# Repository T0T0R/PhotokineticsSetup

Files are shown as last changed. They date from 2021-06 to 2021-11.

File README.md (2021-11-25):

# PhotokineticsSetup
A microcontroller (STM32F103C8) drives at the same time an Hamamatsu lamp through its RS232 interface, and two flip mounts MFF101 via TTL inputs.

## Installation
This script works with Python 3.9.
The pySerial library must be installed in order to achieve serial communication with the microcontroler. This can be done by typing the following command in the system console:
```
python -m pip install pyserial
```
The Tkinter GUI is used in this program. There shouldn't be any need to install it since it is an integral part of most of Python installations.

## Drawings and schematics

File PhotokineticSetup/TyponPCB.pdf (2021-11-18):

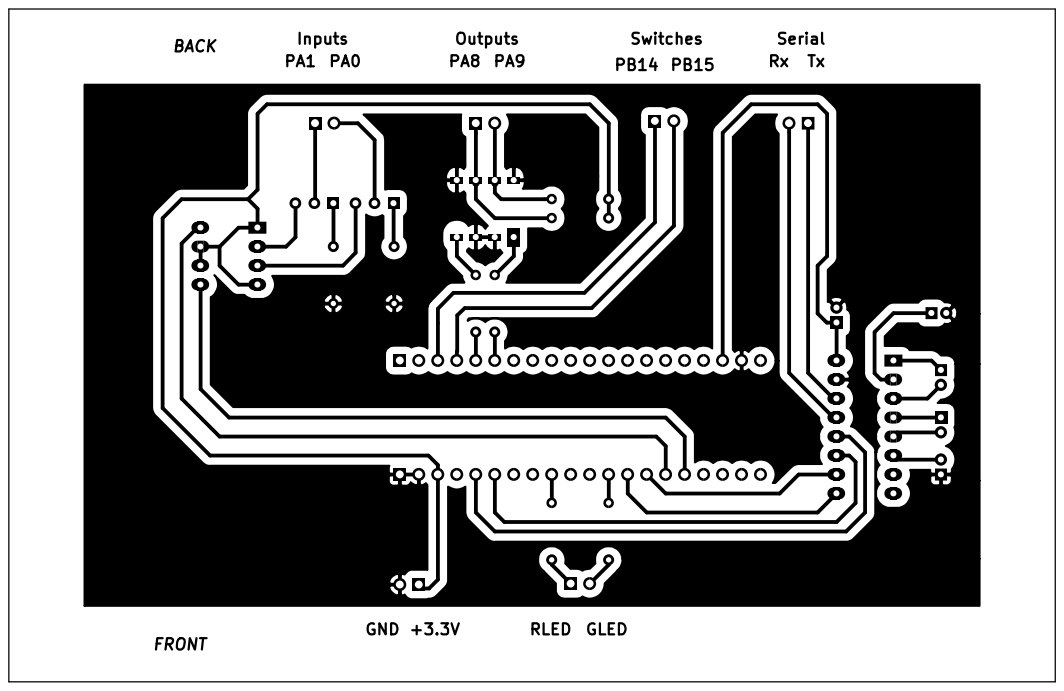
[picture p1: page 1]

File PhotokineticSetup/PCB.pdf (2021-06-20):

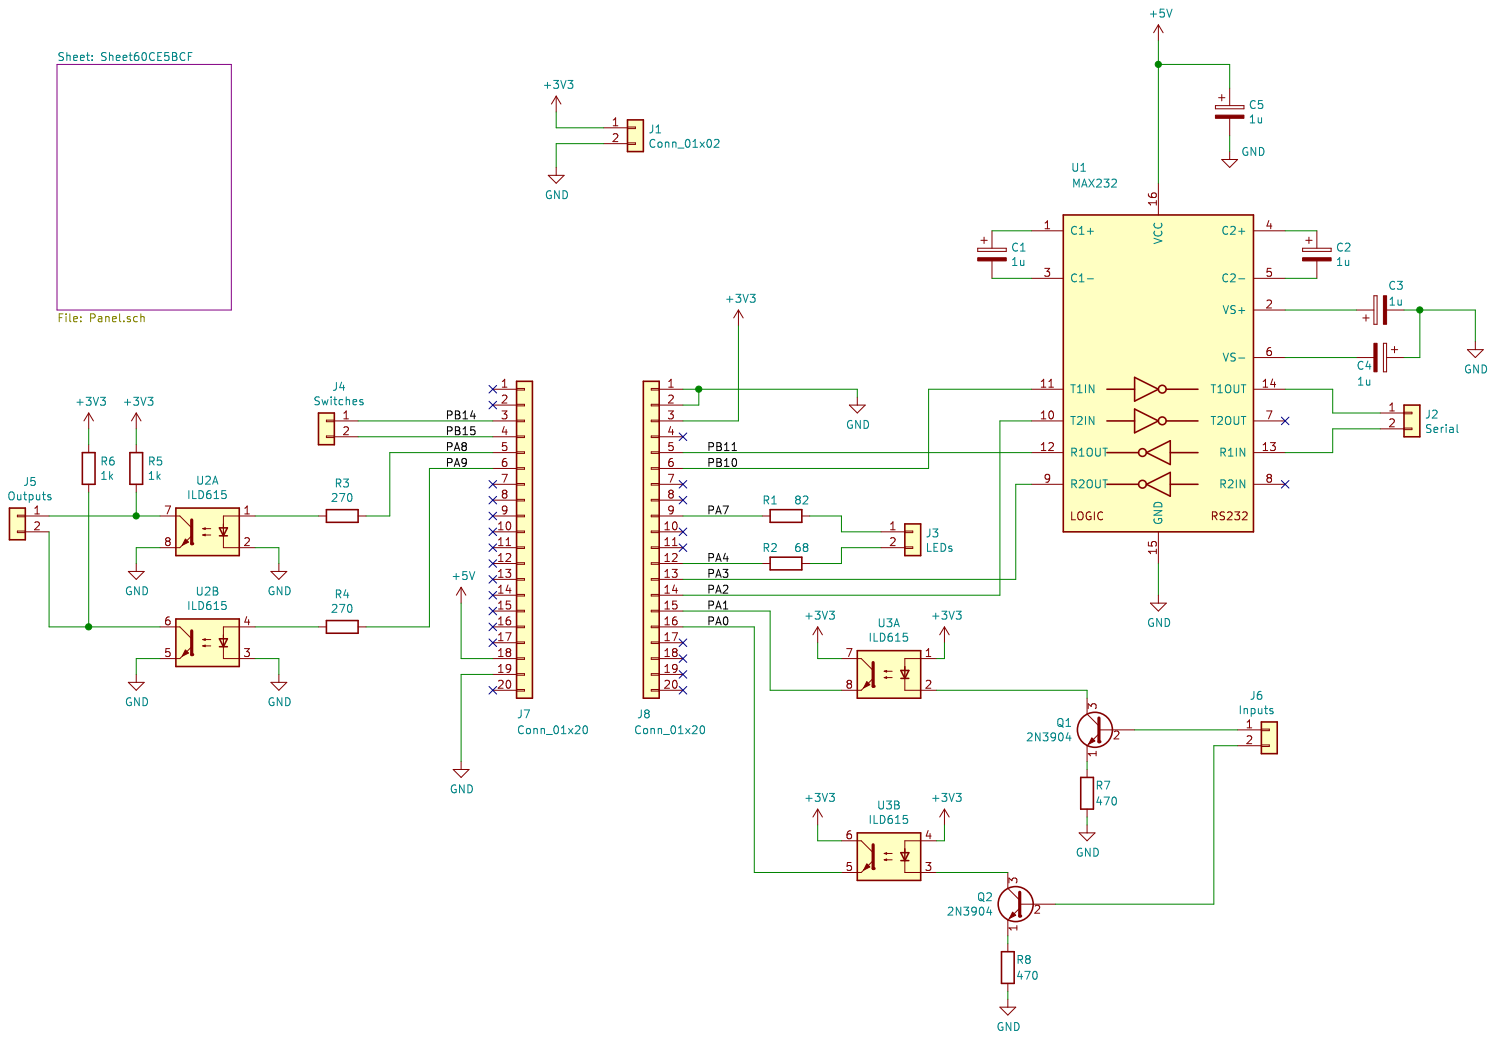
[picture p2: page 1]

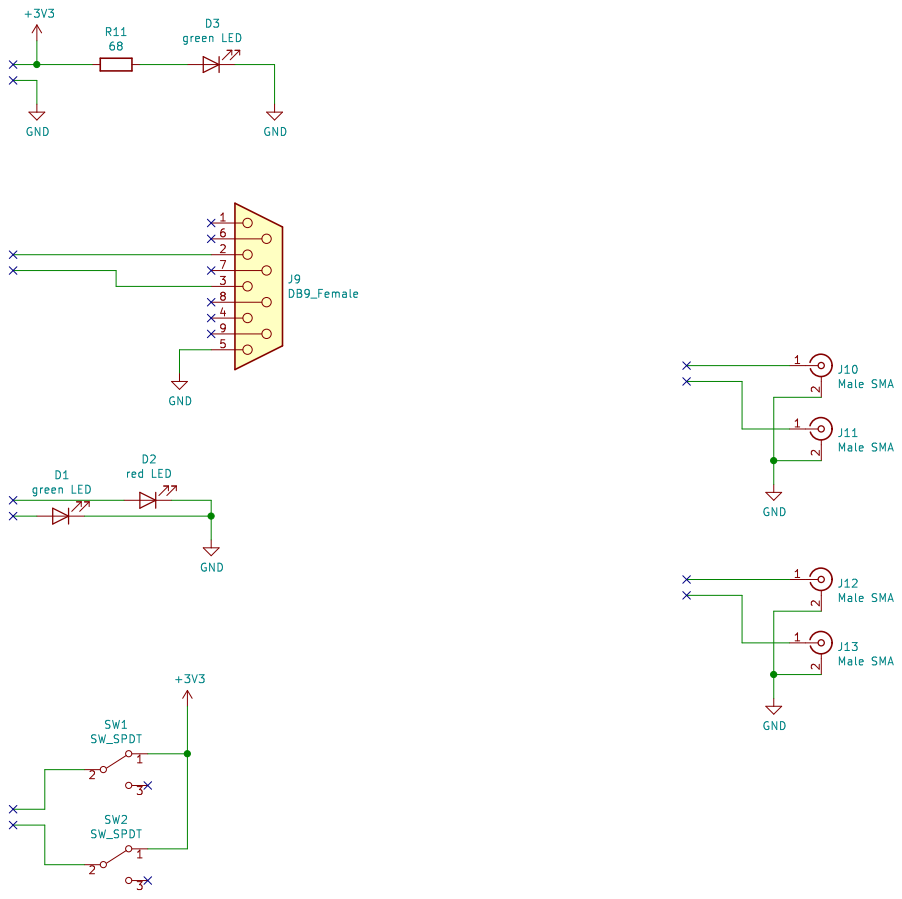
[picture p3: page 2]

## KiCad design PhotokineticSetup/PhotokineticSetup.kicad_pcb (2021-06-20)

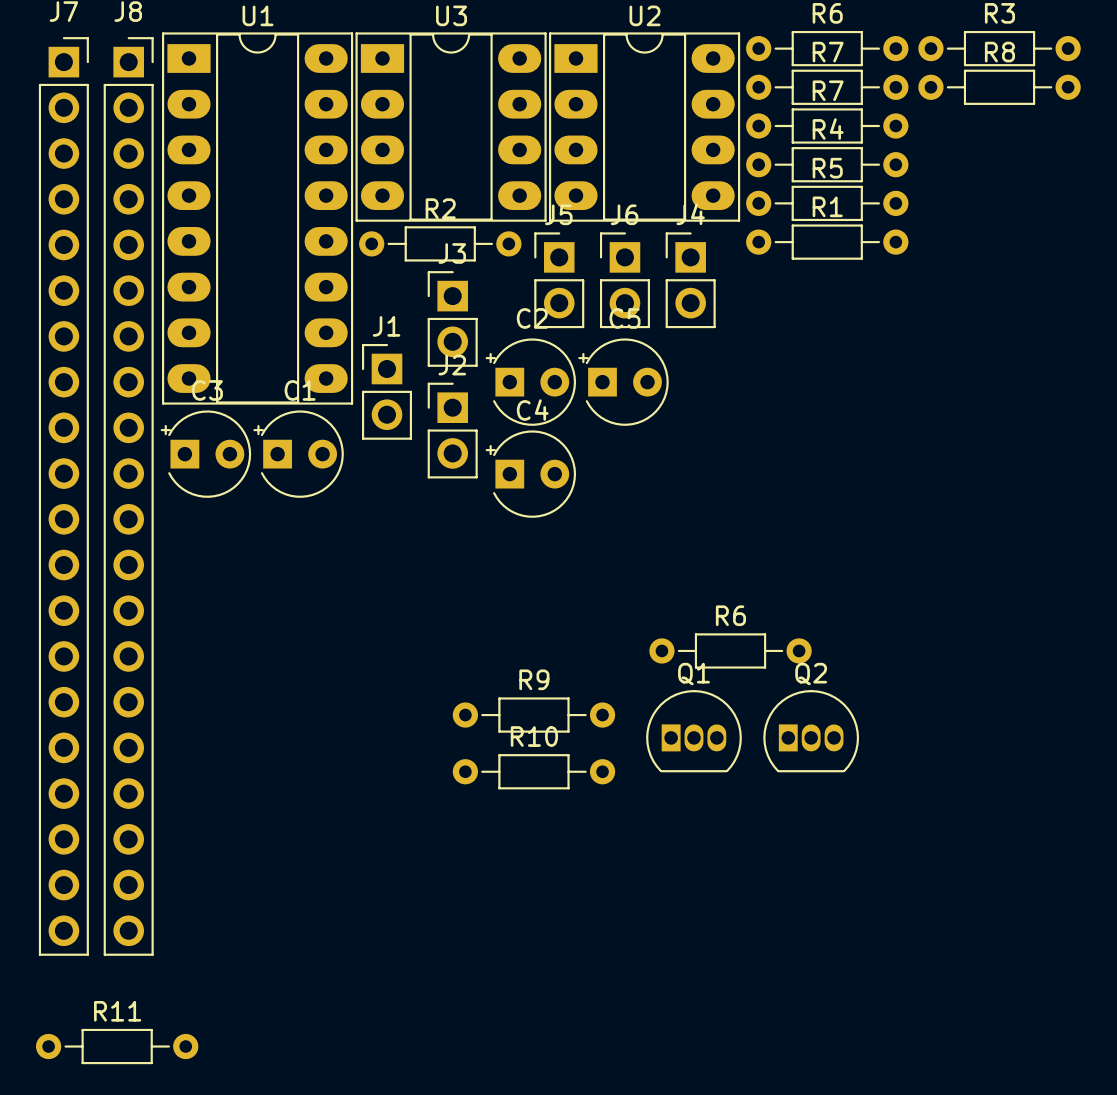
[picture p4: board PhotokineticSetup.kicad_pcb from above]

Board: 2 copper layers, 31 parts (0 on the bottom side), 35 nets, no tracks yet.

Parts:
C1, C2, C3, C4, C5: 1u; CP_Radial_Tantal_D4.5mm_P2.50mm
J1: Conn_01x02; PinHeader_1x02_P2.54mm_Vertical
J2: Serial; PinHeader_1x02_P2.54mm_Vertical
J3: LEDs; PinHeader_1x02_P2.54mm_Vertical
J4: Switches; PinHeader_1x02_P2.54mm_Vertical
J5: Outputs; PinHeader_1x02_P2.54mm_Vertical
J6: Inputs; PinHeader_1x02_P2.54mm_Vertical
J7, J8: Conn_01x20; PinSocket_1x20_P2.54mm_Vertical
Q1, Q2: 2N3904; TO-92_Inline
R1: 82; R_Axial_DIN0204_L3.6mm_D1.6mm_P7.62mm_Horizontal
R2, R11: 68; R_Axial_DIN0204_L3.6mm_D1.6mm_P7.62mm_Horizontal
R3, R4: 270; R_Axial_DIN0204_L3.6mm_D1.6mm_P7.62mm_Horizontal
R5, R6, R9, R10: 1k; R_Axial_DIN0204_L3.6mm_D1.6mm_P7.62mm_Horizontal
R6#2, R7: 10k; R_Axial_DIN0204_L3.6mm_D1.6mm_P7.62mm_Horizontal
R7#2, R8: 470; R_Axial_DIN0204_L3.6mm_D1.6mm_P7.62mm_Horizontal
U1: MAX232; DIP-16_W7.62mm_Socket_LongPads
U2, U3: ILD615; DIP-8_W7.62mm_Socket_LongPads

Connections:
+3V3: J1.1, J8.3, R5.1, R6.1, R11.2, U3.1, U3.4, U3.6, U3.7
+5V: C5.1, J7.18, U1.16
/PA0: J8.16, U3.5
/PA1: J8.15, U3.8
/PA2: J8.14, U1.10
/PA3: J8.13, U1.9
/PA4: J8.12, R2.2
/PA7: J8.9, R1.2
/PA8: J7.5, R3.1
/PA9: J7.6, R4.1
/PB10: J8.6, U1.11
/PB11: J8.5, U1.12
/PB14: J4.1, J7.3
/PB15: J4.2, J7.4
GND: C3.2, C4.1, C5.2, J1.2, J7.19, J8.1, J8.2, R6#2.2, R7.2, R7#2.2, R8.2, U1.15, U2.2, U2.3, U2.5, U2.8
unnamed: C1.1, U1.1
unnamed: C1.2, U1.3
unnamed: C2.1, U1.4
unnamed: C2.2, U1.5
unnamed: C3.1, U1.2
unnamed: C4.2, U1.6
unnamed: J2.1, U1.14
unnamed: J2.2, U1.13
unnamed: J3.1, R1.1
unnamed: J3.2, R2.1
unnamed: J5.1, R5.2, R6#2.1, U2.7
unnamed: J5.2, R6.2, R7.1, U2.6
unnamed: J6.1, Q1.2, R9.1
unnamed: J6.2, Q2.2, R10.1
unnamed: Q1.1, R7#2.1
unnamed: Q1.3, U3.2
unnamed: Q2.1, R8.1
unnamed: Q2.3, U3.3
unnamed: R3.2, U2.1
unnamed: R4.2, U2.4

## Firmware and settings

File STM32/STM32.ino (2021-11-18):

/* Start: April 2021
 *  Interface Serial console / Hamamatsu lamp & motors
 *  UART and RS-232 protocol
 *  Last modification: 25/08/2021
 *  v1.0
 */

#define FILTERA PA8 // Pin used to drive filter A.
#define FA_IS_MOVING PA0     // Pin used to receive the feedback from filter A (LOW if the filter is locked in position).
#define FILTERB PA9 // Pin used to drive filter B.
#define FB_IS_MOVING PA1     // Pin used to receive the feedback from filter B (LOW if the filter is locked in position).

#define SWITCHA PB14  // Switch controlling the position of filter A in manual mode.
#define SWITCHB PB15  // Switch controlling the position of filter B in manual mode.

#define LED_COM PA4  // LED indicating the mechanical activity of filters.
#define LED_MANUAL PA7    // LED indicating that the manual mode is active.


HardwareSerial Serial3(PB11, PB10); // Enables UART communication through serial3 ports (RX3=PB11, TX3=PB10).
//HardwareSerial Serial2(PA3, PA2); // This serial interface was used for debug purposes.


String computerStr = "";  // Stores the message from the computer.
String lampStr = "";      // Stores the message from the lamp.

/*  When manual mode is activated, the computer's instructions to drive filters will be ignored by the microcontroller.
 * Instead, it will drive them accordingly to states of SWITCHA and SWITCHB.
 * When the power is turned on, the default behavior is manual because you may not want to connect the computer to just move a filter.
 */
bool manualMode = true;







/*  This function toggles the state of FILTERA and FILTERB in order to move the connected filters.
 * A LOW signal will switch it to position POS1, ad HIGH to POS2. 
 */
void moveFilter(byte const& filter, byte pos){
  pos = ((pos-1)%2 )+1; // Make sure that the requested position is between 1 and 2.
  
  int filterPin = 0;
  if (filter==1){
    filterPin = FILTERA;
  }else if (filter==2){
    filterPin = FILTERB;
  }
  
  if(pos == 1) digitalWrite(filterPin, LOW);
  else digitalWrite(filterPin, HIGH);

  while (digitalRead(FA_IS_MOVING) || digitalRead(FB_IS_MOVING)){ // Wait until the filter stops moving.
  } 

  if (filter==1){
    Serial.write("MOVAOK\r");
  }else if (filter==2){
    Serial.write("MOVBOK\r");
  }
}










void setup(){
  Serial.begin(9600, SERIAL_8N1);   // Communication with the computer: 9600 bauds, 8 data bits, no parity, one stop bit.
  Serial3.begin(9600, SERIAL_8N1);  // Communication with the Hamamatsu lamp: 9600 bauds, 8 data bits, no parity, one stop bit.
  delay(1000);
  
  pinMode(LED_BUILTIN, OUTPUT);
  pinMode(FILTERA, OUTPUT);  digitalWrite(FILTERA, LOW);
  pinMode(FILTERB, OUTPUT); digitalWrite(FILTERB, LOW);

  pinMode(FA_IS_MOVING, INPUT_PULLDOWN); // If feedback is not connected, filters will be seen as not moving by the microcontroller and so it will not wait for them to stop moving.
  pinMode(FB_IS_MOVING, INPUT_PULLDOWN);
  pinMode(SWITCHA, INPUT_PULLDOWN);
  pinMode(SWITCHB, INPUT_PULLDOWN);

  pinMode(LED_COM, OUTPUT);  digitalWrite(LED_COM, LOW);
  pinMode(LED_MANUAL, OUTPUT);  digitalWrite(LED_MANUAL, LOW); 
}






void loop(){
  digitalWrite(LED_BUILTIN, HIGH);  // Turn off the onboard LED.
  digitalWrite(LED_COM, LOW); // Turn off the LED monitoring the serial transmission.
  

  if(Serial.available()){
    digitalWrite(LED_COM, HIGH);  // Turn on the LED monitoring the serial transmission.
    
    computerStr = Serial.readStringUntil('\r')+'\r'; // Captures the incoming instruction (ending with the '\r' character).

    if(computerStr=="MOVA1\r" && (not manualMode)){  // Check if the received instruction is concerning the filters or the lamp.
      moveFilter(1,1);
    }else if(computerStr=="MOVA2\r" && (not manualMode))  moveFilter(1,2);
    else if(computerStr=="MOVB1\r" && (not manualMode))   moveFilter(2,1);
    else if(computerStr=="MOVB2\r" && (not manualMode))   moveFilter(2,2);
    else if(computerStr=="MAN1\r"){
      manualMode = false;
      Serial.write("MAN1OK\r");
    }
    else if(computerStr=="MAN2\r"){
      manualMode = true;
      Serial.write("MAN2OK\r");
    }
    else{  // If the received instructions do not concern filters, they are passed to the lamp.

      char* buf = (char*) malloc(sizeof(char)*(computerStr.length() + 1)); // Creates a char array buffer to store the string $computerStr$.
      computerStr.toCharArray(buf, computerStr.length() + 1);              // Convert String $computerStr$ to a char array $cString$.


      while (digitalRead(FA_IS_MOVING) || digitalRead(FB_IS_MOVING)){  // If a filter is moving, wait until it stops to send instructions to the lamp. 
      }

      
      Serial3.write(buf);
      free(buf);
        
    }
  }



  if (manualMode){  // In manual mode, check states of switches to drive filters.
    digitalWrite(LED_MANUAL, HIGH);
    digitalWrite(FILTERA, digitalRead(SWITCHA));
    digitalWrite(FILTERB, digitalRead(SWITCHB));
  }else{
    digitalWrite(LED_MANUAL, LOW);
  }
  

 
  //  Transmits messages from the lamp to the computer.
  while(Serial3.available()){
    digitalWrite(LED_COM, HIGH);  // Turn on the LED monitoring the serial transmission.
    Serial.write(Serial3.read());
  }

delay(10);
}

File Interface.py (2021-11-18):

from datetime import datetime
import time
import serial
import serial.tools.list_ports
import tkinter as tk
import tkinter.ttk as ttk
import os
from threading import Thread






class SerialCommunication:
    '''
       Class managing the communication with the lamp over a serial port.
    '''
   
    
    def __init__(self):
        self.socketDefined = False # Is the serial port defined by the user yet ?
        self.shutterOpened = False # Is lamp shutter open ?


    # Define the port used for this serial communication.
    def definePort(self, serialPort):   # Use of "try...except" to avoid crashing if the selected port is incorrect.
        try:
            self.ser = serial.Serial(str(serialPort))
            self.socketDefined = True
        except serial.serialutil.SerialException:
            raise serial.serialutil.SerialException("Incorrect name port")        
    
    
    # Begin the communication with the lamp.
    def begin(self):
        self.reset()
    
    
    # Stops the communication with the lamp.
    def stop(self):
        if self.socketDefined:
            self.ser.write("PROG_7STEP\r".encode()) # Set the mode of the lamp back to 7-step (this mode is the one that is usually used when the lamp is turned on).
            self.ser.close()
    
    
    # Series of instruction to ensure that the microcontroller and the lamp will receive and execute commands.
    def reset(self):
        self.send("MAN1\r")         # Turning off the manual mode of the interface,
        self.send("INP\r")          # maybe not useful,
        self.send("CNT1\r")         # control of the lamp via commands,
        self.send("PROG_1STEP\r")   # set the program mode to 1-step in order to use INTSET*** later.

    
    # Changes the state of the irradiation (light on/off, filter used, intensity).
    def irradiate(self, activate, intensity, filterA, filterB):
        if activate:
            self.moveFilterA(int(filterA))
            self.moveFilterB(int(filterB))
            self.intSet(intensity)
            
            prevTime = time.time()
            while time.time() - prevTime < 5: pass   # Wait for the intensity to reach the command (about 5 sec).            
            
            self.shutterOpen()
        else:
            #print("should see SO")
            self.shutterClose()    
    
    
    # Set the intensity of the lamp/
    def intSet(self, intensity):
        perc = f'{int(intensity):03}'
        self.send("INTSET"+perc+"\r")
    
    
    # Closes the shutter of the lamp.
    def shutterClose(self):
        if self.shutterOpened:
            self.send("S0\r")
            self.shutterOpened = False
    
    
    # Opens the shutter of the lamp. 
    def shutterOpen(self):
        if not self.shutterOpened:
            self.send("S1\r")
            self.shutterOpened = True
    
    
    # Moves the filter A.
    def moveFilterA(self, pos):
        self.send("MOVA"+str(pos)+"\r")
    
    
    # Moves the filter B.
    def moveFilterB(self, pos):
        self.send("MOVB"+str(pos)+"\r")
               
    
    # Send a String to the serial port.
    def send(self, string):
        print(string)   # For debug purposes, this line can be removed.
        MyLog.write(string[:-1])
        self.ser.write(string.encode()) # Converts the unicode string into a byte string.
    
    
    # Returns the state of the serial socket.  
    def isDefined(self):
        return self.socketDefined
    
    
    # Returns the name of the port used for serial communication.
    def getPort(self):
        return self.ser.port
        
        







class Step:
    '''
       This class contains informations corresponding to one step of irradiation.
    '''
    
    stepNo = 0     # Number of the step.
    duration = 0   # Duration of the step.
    perc = 0       # Light intensity of the step.
    filterA = 0    # Position of the filter A.
    filterB = 0    # Position of the filter B.
    test = False   # Test this step by turning on the lamp outside the irradiation sequence to adjust parameters.
    
    
    def __init__(self, s=0, p=0, d=0, A=0, B=0, test=False):
        self.stepNo = s
        self.perc = p
        self.duration = d
        self.filterA = A
        self.filterB = B
        self.test = False
    
    
    # Update the parameters of this step with new values.
    def update(self, intensity, duration, FA, FB, v):
        self.duration = duration
        self.perc = intensity
        self.filterA = FA
        self.filterB = FB
        if v==self.stepNo:
            self.test = True
        else:
            self.test = False
        
        if App._thread is None:
            MySerial.irradiate(self.test, self.perc, self.filterA, self.filterB)
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

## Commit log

2021-06-14 Add schematic diagrams
    [Panel.sch, PhotokineticSetup.kicad_pcb, PhotokineticSetup.sch]
2021-06-16 Clearer optocouplers outputs and stronger input
    [Panel.sch, PhotokineticSetup.kicad_pcb, PhotokineticSetup.sch]
2021-06-16 LED resistors calculated according to forward voltage
    [Panel.sch, PhotokineticSetup.kicad_pcb, PhotokineticSetup.sch]
2021-06-20 Missing GND node + better placement of R7 & R8
    [PhotokineticSetup.kicad_pcb, PhotokineticSetup.sch]
2021-11-18 Threading of the irradiation methods. Keeps a log file.
2021-11-18 Mask layer for the PCB
2021-11-18 Bug fixes.
    Sequence can be started after testing an irradiation step of toggling the manual mode off.
    [Interface.py]
2021-11-18 Correct naming of outputs.
    [STM32.ino]
